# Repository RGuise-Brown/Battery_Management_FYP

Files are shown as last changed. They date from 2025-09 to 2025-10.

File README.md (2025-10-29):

# Battery Monitoring System for Lithium Thionyl Chloride Batteries

A battery monitoring system designed to track the health and state of charge of lithium thionyl chloride batteries operating in extreme cold conditions in the Southern Ocean Marginal Ice Zone (SO MIZ).

## Project Overview

This project was completed as a final year project (EEE4022S) for a Mechatronics Engineering degree at the University of Cape Town (UCT) in 2025.

**Author**: Rachael Guise-Brown  
**Supervisor**: Robyn Verrinder  
**Institution**: University of Cape Town

## Application

This battery monitoring system was designed for the **SHARC (Southern Hemisphere Antarctic Research Collective) Buoy**, which operates in the Southern Ocean Marginal Ice Zone. The system focuses on monitoring battery health in extreme cold conditions and adjusts the expected state of charge based on temperature changes.

## Battery Technology

Lithium thionyl chloride (Li-SOCl₂) batteries present unique monitoring challenges:
- **Primary battery** (non-rechargeable)
- **Very flat voltage discharge curve** - voltage alone is insufficient for accurate SOC estimation
- **Temperature-dependent performance** - capacity varies significantly with temperature

Due to these characteristics, the system uses **coulomb counting** and other methods to estimate state of charge, particularly important in the cold operating conditions of the Southern Ocean.

## System Features

### Hardware
- **INA226 Power Monitor**: Fully implemented and calibrated for accurate current and power measurement
- **BQ35100 Fuel Gauge**: Partial implementation but challenges with calibration and configuration without evaluation module (EVM)
- **Temperature Monitoring**: Three sensors tested
  - TMP117 digital I2C sensor
  - TMP36 (TO-92) analog sensor
  - TMP36 with shutdown (SOT-23) analog sensor (chosen sensor)
- **STM32 Nucleo-L4R5ZI**: Main microcontroller platform

### Firmware
- Real-time current, voltage, and capacity monitoring
- Temperature-compensated state of charge estimation
- Multiple algorithm implementations for data analysis
- I2C communication with all sensors
- Support for BQ35100 mode switching (EOS/ACC)
- Discharge cycle testing capabilities

## Repository Structure

```
├── firmware/          # Embedded C code for STM32
├── hardware/          # KiCad PCB designs and schematics
└── docs/              # Datasheets and reference documentation
```

## Implementation Status

### Fully Implemented ✓
- INA226 power monitor with calibration
- Temperature sensor array (TMP117, TMP36 sensors)
- BQ35100 basic functionality:
  - Current, voltage, and capacity reading
  - Mode switching (EOS ↔ ACC)
  - EOS impedance measurements (uncalibrated)
- Real-time monitoring algorithms
- Temperature-compensated SOC estimation

### Known Limitations
- BQ35100 I2C calibration is not functional through firmware

## Getting Started

### Hardware Setup
1. Review the hardware designs in `/hardware`
2. Assemble or obtain the custom PCBs:
   - BQ35100 fuel gauge board
   - Temperature sensor board
   - STM32 Nucleo Hat with INA226
3. Connect boards to STM32 Nucleo-L4R5ZI

### Firmware Setup
1. Navigate to `/firmware` directory
2. Build and flash the firmware to the STM32 Nucleo-L4R5ZI
3. Configure parameters as needed for your battery specifications

### Documentation
Refer to `/docs` for component datasheets and reference materials.

## Key Technologies

- **Microcontroller**: STM32L4R5ZI (ARM Cortex-M4)
- **Development Environment**: ARM GCC toolchain, STM32CubeIDE
- **Hardware Design**: KiCad
- **Communication Protocols**: I2C, UART
- **Programming Language**: C

## License

This project is licensed under the MIT License - see the LICENSE file for details.

## Acknowledgments

- **Robyn Verrinder** - Project supervisor
- **University of Cape Town** - Department of Electrical Engineering
- **SHARC Project** - Application context and requirements
- **Texas Instruments** - BQ35100 and INA226 reference designs

## Contact

Rachael Guise-Brown  
University of Cape Town  
2025

---

*Final Year Project (EEE4022S) - Mechatronics Engineering*  
*University of Cape Town*

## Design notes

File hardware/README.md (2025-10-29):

# Hardware Documentation

Hardware design files for the Battery Monitoring System, including custom PCB designs created in KiCad.

## Overview

Three main PCB designs that integrate with an STM32 Nucleo-L4R5ZI development board to create a complete battery monitoring solution.

## PCB Designs

### 1. STM32 Nucleo Hat (STM_Nucleo_Hat)
Board borrowed from ARU that contains INA226 power monitor which is the only component used in this project.

**Files**: Located in `/STM_Nucleo_Hat/` directory

---

### 2. BQ35100 Board (FYP_PMIC)
Custom board featuring the Texas Instruments BQ35100 fuel gauge for battery monitoring.

**Files**: Located in `/FYP_PMIC/` directory

---

### 3. Temperature Sensor Board (FYP_temp)
Custom board with three temperature sensors:
- TMP117 (digital I2C sensor)
- TMP36 (TO-92 analog sensor)
- TMP36 with shutdown (SOT-23 analog sensor)

**Files**: Located in `/FYP_temp/` directory

---

## Schematics

Full schematics are provided in both PDF and image formats for easy viewing:

### BQ35100 Board
- `BQ35100 Schematic.pdf` - Full schematic documentation
- `BQ35100 Schematic.png` - Quick reference image

### INA226 Board
- `INA226 Full Board Schematic.pdf` - Complete board schematic
- `INA226 Schematic.jpeg` - Quick reference image

### Temperature Sensor Board
- `Temp Board Schematic.pdf` - Full schematic documentation
- `Temp Schematic.png` - Quick reference image

## KiCad Component Files

Custom component libraries and footprints are located in the `/KiCad component files/` directory. These include:
- Custom symbols for BQ35100, INA226, and temperature sensors

## Design Tools

**Software**: KiCad 6.0 or later

## Getting Started

Open the `.kicad_pro` file in the respective board directory, or view the PDF schematics directly.

## Component Information

**Key ICs Used**:
- INA226 power monitor (on STM Nucleo Hat)
- BQ35100 fuel gauge
- TMP117 digital temperature sensor
- TMP36 analog temperature sensors (x2)

**Microcontroller**: STM32 Nucleo-L4R5ZI development board

## Notes

- INA226 is fully implemented and calibrated
- BQ35100 has partial implementation (see firmware README for details)
- All designs created in KiCad

---

For firmware documentation, see the main repository README.

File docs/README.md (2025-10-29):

# Documentation & Datasheets

Reference documentation and datasheets for components used in the Battery Monitoring System.

## Component Datasheets

### Battery Monitoring ICs
- **bq35100.pdf** - Texas Instruments BQ35100 fuel gauge datasheet
- **ina226.pdf** - Texas Instruments INA226 power monitor datasheet
- **ina219.pdf** - Texas Instruments INA219 power monitor datasheet

### Temperature Sensors
- **tmp117.pdf** - TMP117 digital temperature sensor datasheet
- **tmp36.pdf** - TMP36 analog temperature sensor datasheet

### Microcontroller
- **stm32l4r5vi.pdf** - STM32L4R5VI microcontroller datasheet
- **nucleo-l4r5zi-p.pdf** - STM32 Nucleo-L4R5ZI development board datasheet

## Reference Documents

### Texas Instruments Application Notes
- **sluubh1c.pdf** - BQ35100 technical reference
- **sluubh7.pdf** - BQ35100 application guide

### STM32 Documentation
- **um2179-stm32-nucleol44-boards-mb1312-stmicroelectronics.pdf** - STM32 Nucleo board user manual
- **rm0432-stm32l4-series-advanced-armbased-32bit-mcus-stmicroelectroni...** - STM32L4 series reference manual (memory mapping)

## Usage

Refer to these datasheets when:
- Configuring hardware components
- Understanding I2C communication protocols
- Setting up calibration parameters
- Troubleshooting hardware issues
- Designing custom PCBs

---

For hardware designs, see the hardware folder. For firmware implementation, see the main repository README.

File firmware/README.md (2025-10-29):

# Battery Monitoring System

A comprehensive battery monitoring system implementation with support for multiple temperature sensors, INA226 power monitor, and BQ35100 fuel gauge integration for real-time battery parameter tracking and analysis.

## Overview

This project implements a complete battery monitoring system designed for embedded applications. It provides real-time battery voltage, current, capacity, and temperature monitoring with support for multiple sensor types and monitoring algorithms.

## Key Features

- **Multi-Sensor Temperature Monitoring**: 
  - TMP117 digital temperature sensor
  - TMP36 (TO-92 package) analog temperature sensor
  - TMP36 with shutdown (SOT-23 package) analog temperature sensor
- **INA226 Power Monitor**: Fully implemented and calibrated for accurate current and power measurement
- **BQ35100 Fuel Gauge**: Partial implementation with working features:
  - Current, voltage, and capacity readings
  - Mode switching between EOS (End-of-Service) and ACC (Accumulator) modes
  - EOS impedance and scaled impedance measurement
  - Note: I2C calibration not yet functional
- **Real-time Monitoring**: Continuous battery voltage, current, and temperature tracking
- **Advanced Algorithms**: Multiple monitoring algorithm implementations for data analysis
- **I2C Communication**: Robust I2C interface for all sensor communication
- **Temperature Protection**: Multi-point temperature sensing with threshold monitoring
- **Discharge Cycle Testing**: Automated discharge cycle testing capabilities
- **System Monitoring**: Comprehensive system health monitoring and logging

## Project Structure

### Core Monitoring Files
Uses the individual component files to create a single file that reads all of the values.

- **bms_monitor_reduced.c/h** -  Monitoring implementation for INA226 and TMP36 (SOT-23)
- **bms_monitor.c/h** - Monitoring implementation for BQ35100 and TMP36 (SOT-23)

### Core Algorithm Files
Monitoring algorithms to track, temperature adjusted state-of-charge, voltage drop during high current transmissions, voltage throughout discharge and temperature trend
- **bms_algorithms_v2.c/h** - Version 2 of monitoring algorithms with improvements
- **bms_algorithms.c/h** - Monitoring algorithm implementation version 1, designed for BQ35100 with EOS but not fully tested without EOS calibration

### Hardware Interface

#### Battery Monitoring ICs

**INA226 Power Monitor** (Fully Implemented ✓)
- **ina226_i2c1.c/h** - Complete INA226 interface with calibration
- Accurate current, voltage, and power measurements
- Fully calibrated and operational

**BQ35100 Fuel Gauge** (Partially Implemented)
- **bq35100_i2c_acc.c/h** - BQ35100 accumulator mode interface
- **bq35100_i2c_eos.c/h** - BQ35100 end-of-service mode interface
- **bq35100_common.h** - Common definitions for BQ35100
- Working features:
  - Current, voltage, and capacity reading
  - Mode switching (EOS ↔ ACC)
  - EOS impedance and scaled impedance measurement
- Known limitations:
  - I2C calibration not functional

#### Temperature Sensors

- **TMP117** - Digital I2C temperature sensor
- **TMP36 (TO-92)** - Analog temperature sensor
- **TMP36 with Shutdown (SOT-23)** - Analog temperature sensor with power control

#### Communication Interfaces

- **i2c.c/h** - Generic I2C communication layer
- **i2c_temp.c/h** - I2C temperature sensor interface
- **adc_temp.c/h** - ADC-based temperature measurement (for analog sensors)

### Monitoring & Testing

- **battery_monitor.c/h** - Main battery monitoring module
- **battery_monitor_reduced.h** - Reduced footprint monitoring
- **system_monitoring.c/h** - Overall system health monitoring
- **discharge_cycle_test.c/h** - Automated discharge testing
- **rapid_transmission_test.c** - High-speed data transmission testing
- **monitoring_testing.c** - Monitoring system validation

### System Components

- **main.c** - Main application entry point
- **clock_config.c/h** - System clock configuration
- **uart.c/h** - UART communication interface
- **led.c/h** - LED status indicators
- **syscalls.c** - System call implementations
- **systick_timing.c/h** - System tick timing utilities

### Utilities

- **adc_temp.c/h** - ADC-based temperature measurement
- **temp_sensor_enable.c/h** - Temperature sensor control
- **temp_threshold_test.c/h** - Temperature threshold testing

## Hardware Requirements

### Microcontroller
- STM32 Microcontroller (configured via clock_config)

### Battery Monitoring ICs
- **INA226** - Power monitor (fully supported)
- **BQ35100** - Fuel gauge (partial support)

### Temperature Sensors
- **TMP117** - Digital I2C temperature sensor
- **TMP36 (TO-92)** - Analog temperature sensor
- **TMP36 (SOT-23)** - Analog temperature sensor with shutdown capability

### Peripherals
- LED indicators for status
- UART interface for debugging and data output

## Getting Started

### Prerequisites

- ARM GCC toolchain
- STM32 development environment
- Hardware setup with required sensors

### Building

```bash
# Clone the repository
git clone [your-repo-url]

# Build the project
make all
```

### Configuration

1. Configure clock settings in `clock_config.c`
2. Set up I2C bus parameters in `i2c.c`
3. Configure monitoring algorithm parameters in `bms_algorithms.h`
4. Adjust temperature thresholds in `temp_threshold_test.h`
5. Calibrate INA226 settings in `ina226_i2c1.c` (already calibrated)
6. Configure BQ35100 mode settings (EOS/ACC) as needed

**Note**: BQ35100 I2C calibration is not currently functional and may require manual calibration through other means.

## Usage

The system initializes all peripherals and begins continuous monitoring upon startup. Battery data can be accessed via:

- UART interface for real-time debugging
- LED indicators for status
- System monitoring interface for detailed metrics

## Testing

The project includes several test modules:

- **Discharge Cycle Test**: Validates battery behavior during discharge
- **Rapid Transmission Test**: Tests high-speed data communication
- **Temperature Threshold Test**: Verifies thermal protection
- **Monitoring Testing**: Validates monitoring accuracy

## Algorithm Versions

This project contains multiple monitoring algorithm implementations:

- **Original** (`bms_algorithms.c`) - Initial implementation
- **Version 2** (`bms_algorithms_v2.c`) - Refined algorithms with improved accuracy

## Implementation Status

### Fully Implemented ✓
- INA226 power monitor with calibration
- TMP117 digital temperature sensor
- TMP36 analog temperature sensors (both variants)
- Mode switching for BQ35100 (EOS/ACC)
- Basic BQ35100 reading (current, voltage, capacity)
- EOS impedance measurements

### Partially Implemented ⚠️
- BQ35100 I2C calibration (not functional)

## Acknowledgments

- Texas Instruments for BQ35100 documentation
- STMicroelectronics for STM32 support

---

**Last Updated**: October 2025

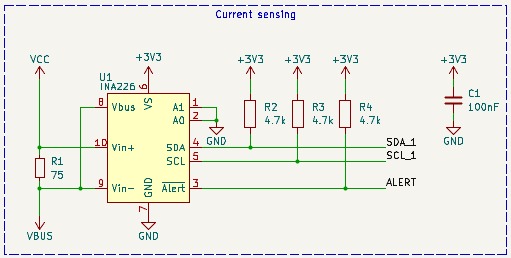
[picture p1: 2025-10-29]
hardware/INA226 Schematic.jpeg

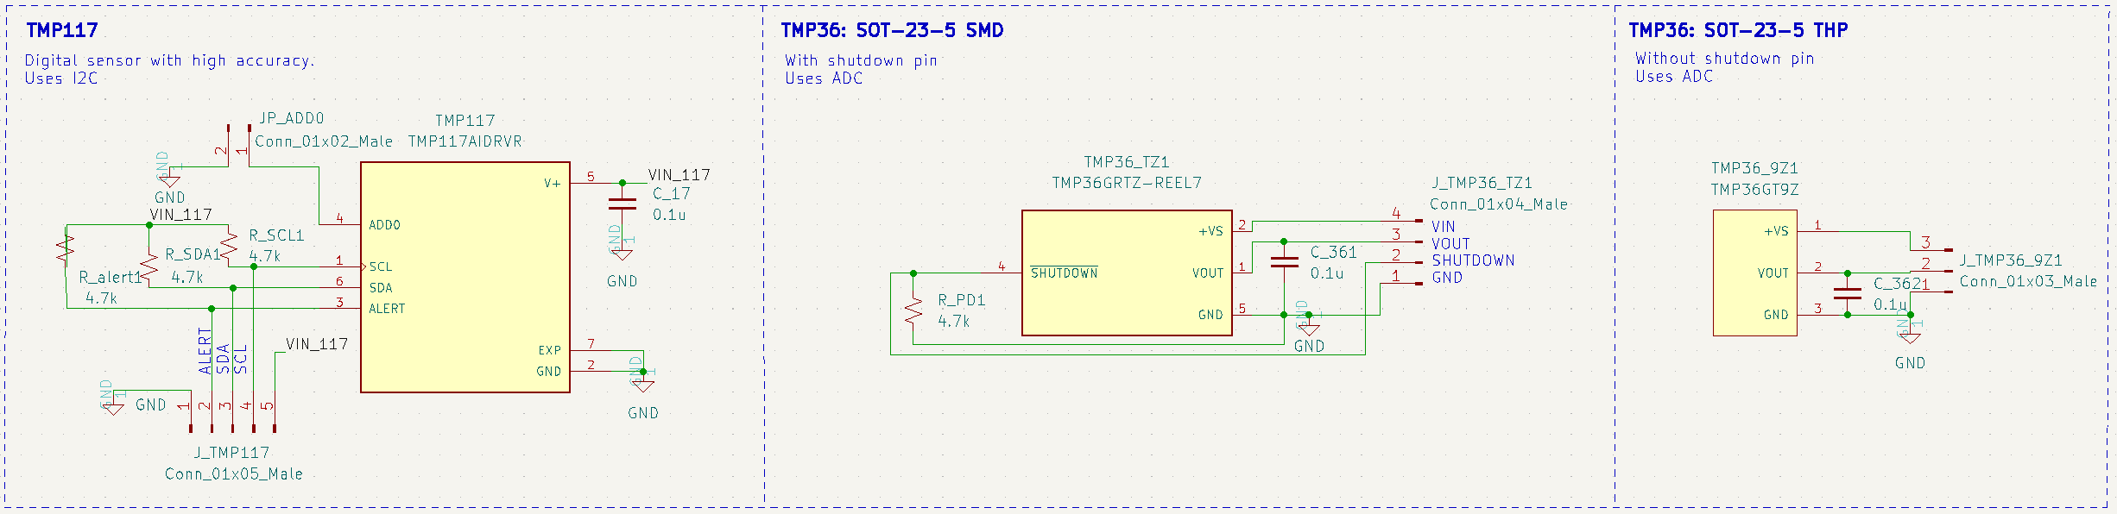
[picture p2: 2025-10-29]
hardware/Temp Schematic.png

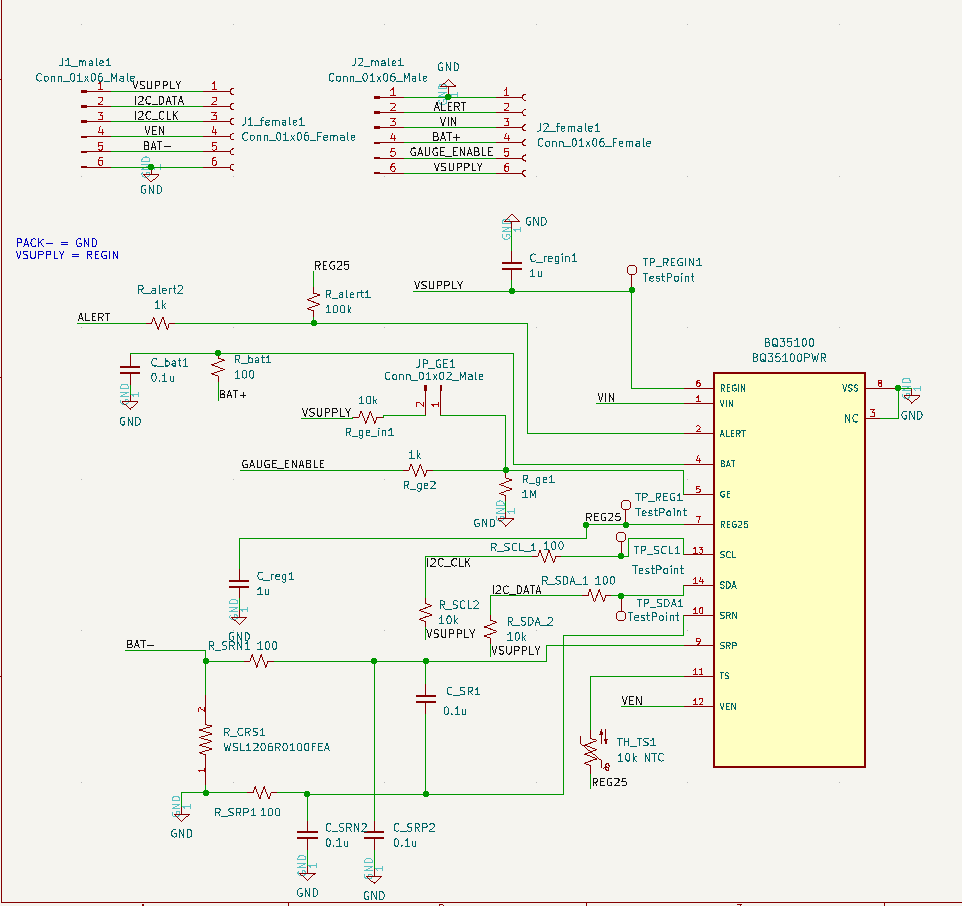
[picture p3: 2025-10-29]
hardware/BQ35100 Schematic.png

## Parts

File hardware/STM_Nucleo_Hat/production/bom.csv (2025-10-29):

Designator | Footprint | Quantity | Value | LCSC Part #
C1, C2 | 0603 | 2 | 100nF | C14663
R1 | 0805 | 1 | 75 | C3033913
R2, R3, R4 | 0603 | 3 | 4.7k | C23162
U1 | MSOP-10_3x3mm_P0.5mm | 1 | INA226 | C49851

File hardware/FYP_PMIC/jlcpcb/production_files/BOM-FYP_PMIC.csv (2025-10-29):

Comment | Designator | Footprint | LCSC
0.1u | C_SR1,C_SRN2,C_SRP2,C_bat1 | C_0402_1005Metric | C1525
1u | C_reg1,C_regin1 | C_0603_1608Metric | C15849
100 | R_SCL_1,R_SDA_1,R_SRN1,R_SRP1,R_bat1 | R_0805_2012Metric | C17408
10k | R_SCL2,R_SDA_2,R_ge_in1 | R_0805_2012Metric | C17414
100k | R_alert1 | R_1206_3216Metric | C17900
1M | R_ge1 | R_1206_3216Metric | C17927
1k | R_alert2,R_ge2 | R_1206_3216Metric | C4410
BQ35100PWR | BQ35100 | SOP65P640X120-14N | C469863
WSL1206R0100FEA | R_CRS1 | RESC3216X90 | C843879
TestPoint | TP_SCL1 | TestPoint_Pad_D2.0mm
10k NTC | TH_TS1 | C_Disc_D5.0mm_W2.5mm_P2.50mm
Conn_01x06_Female | J2_female1 | PinSocket_1x06_P2.54mm_Vertical
TestPoint | TP_REGIN1 | TestPoint_Pad_D2.0mm
Conn_01x02_Male | JP_GE1 | PinHeader_1x02_P2.54mm_Vertical
Conn_01x06_Male | J1_male1 | PinHeader_1x06_P2.54mm_Vertical
TestPoint | TP_REG1 | TestPoint_Pad_D2.0mm
TestPoint | TP_SDA1 | TestPoint_Pad_D2.0mm
Conn_01x06_Male | J2_male1 | PinHeader_1x06_P2.54mm_Vertical
Conn_01x06_Female | J1_female1 | PinSocket_1x06_P2.54mm_Vertical

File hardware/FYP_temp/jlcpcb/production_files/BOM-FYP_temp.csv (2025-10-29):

Comment | Designator | Footprint | LCSC
0.1u | C_17,C_361,C_362 | C_0402_1005Metric | C1525
4.7k | R_PD1,R_SCL1,R_SDA1,R_alert1 | R_0603_1608Metric | C23162
TMP36GT9Z | TMP36_9Z1 | TO92127P521H733-3 | C5692995
TMP36GRTZ-REEL7 | TMP36_TZ1 | SOT95P280X145-5N | C5692996
TMP117AIDRVR | TMP117 | SON65P200X200X80-7N | C699536
Conn_01x04_Male | J_TMP36_TZ1 | PinHeader_1x04_P2.54mm_Vertical
Conn_01x02_Male | JP_ADD0 | PinHeader_1x02_P2.54mm_Vertical
Conn_01x05_Male | J_TMP117 | PinHeader_1x05_P2.54mm_Vertical
Conn_01x03_Male | J_TMP36_9Z1 | PinHeader_1x03_P2.54mm_Vertical

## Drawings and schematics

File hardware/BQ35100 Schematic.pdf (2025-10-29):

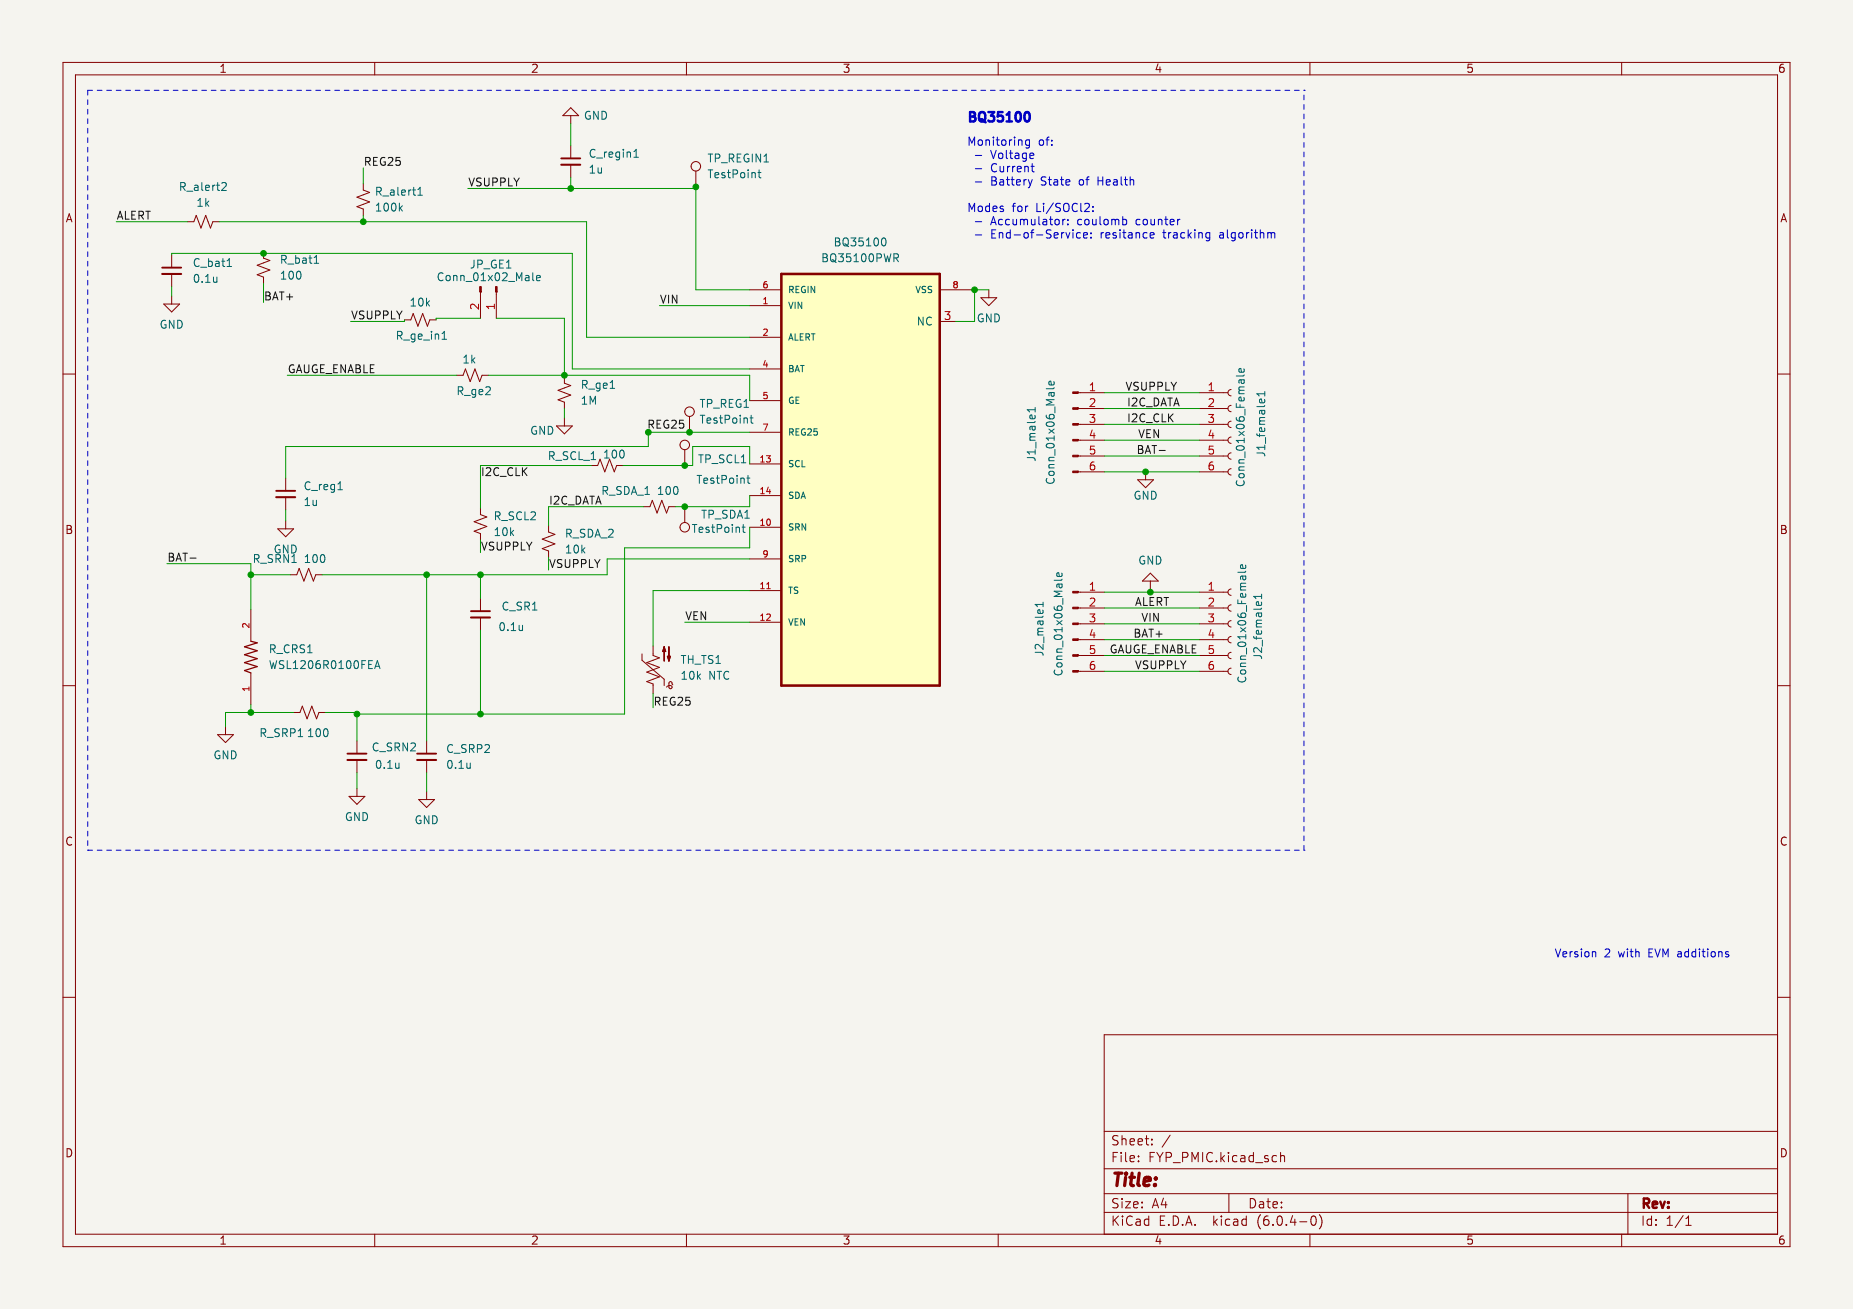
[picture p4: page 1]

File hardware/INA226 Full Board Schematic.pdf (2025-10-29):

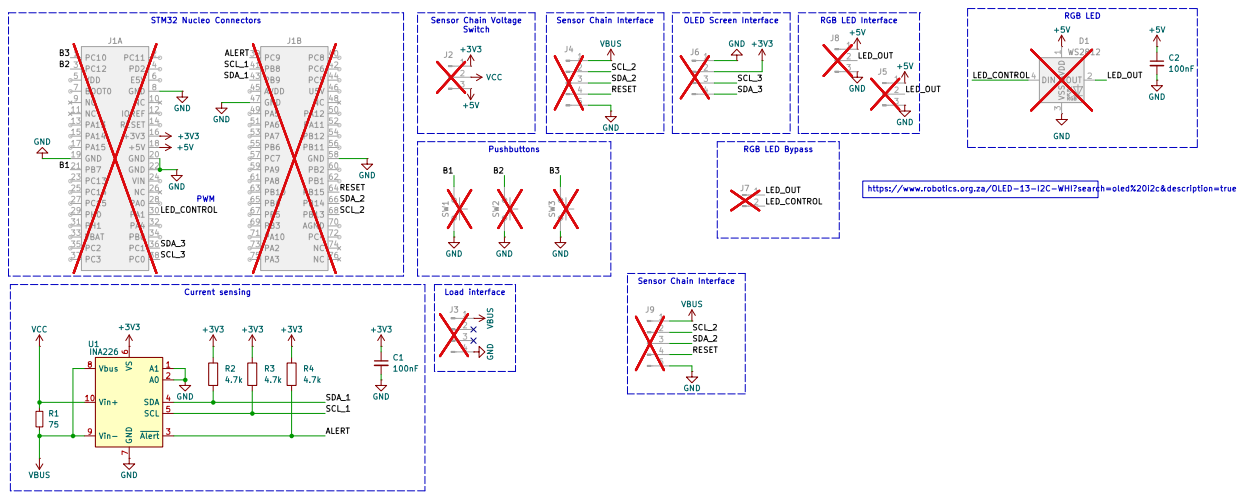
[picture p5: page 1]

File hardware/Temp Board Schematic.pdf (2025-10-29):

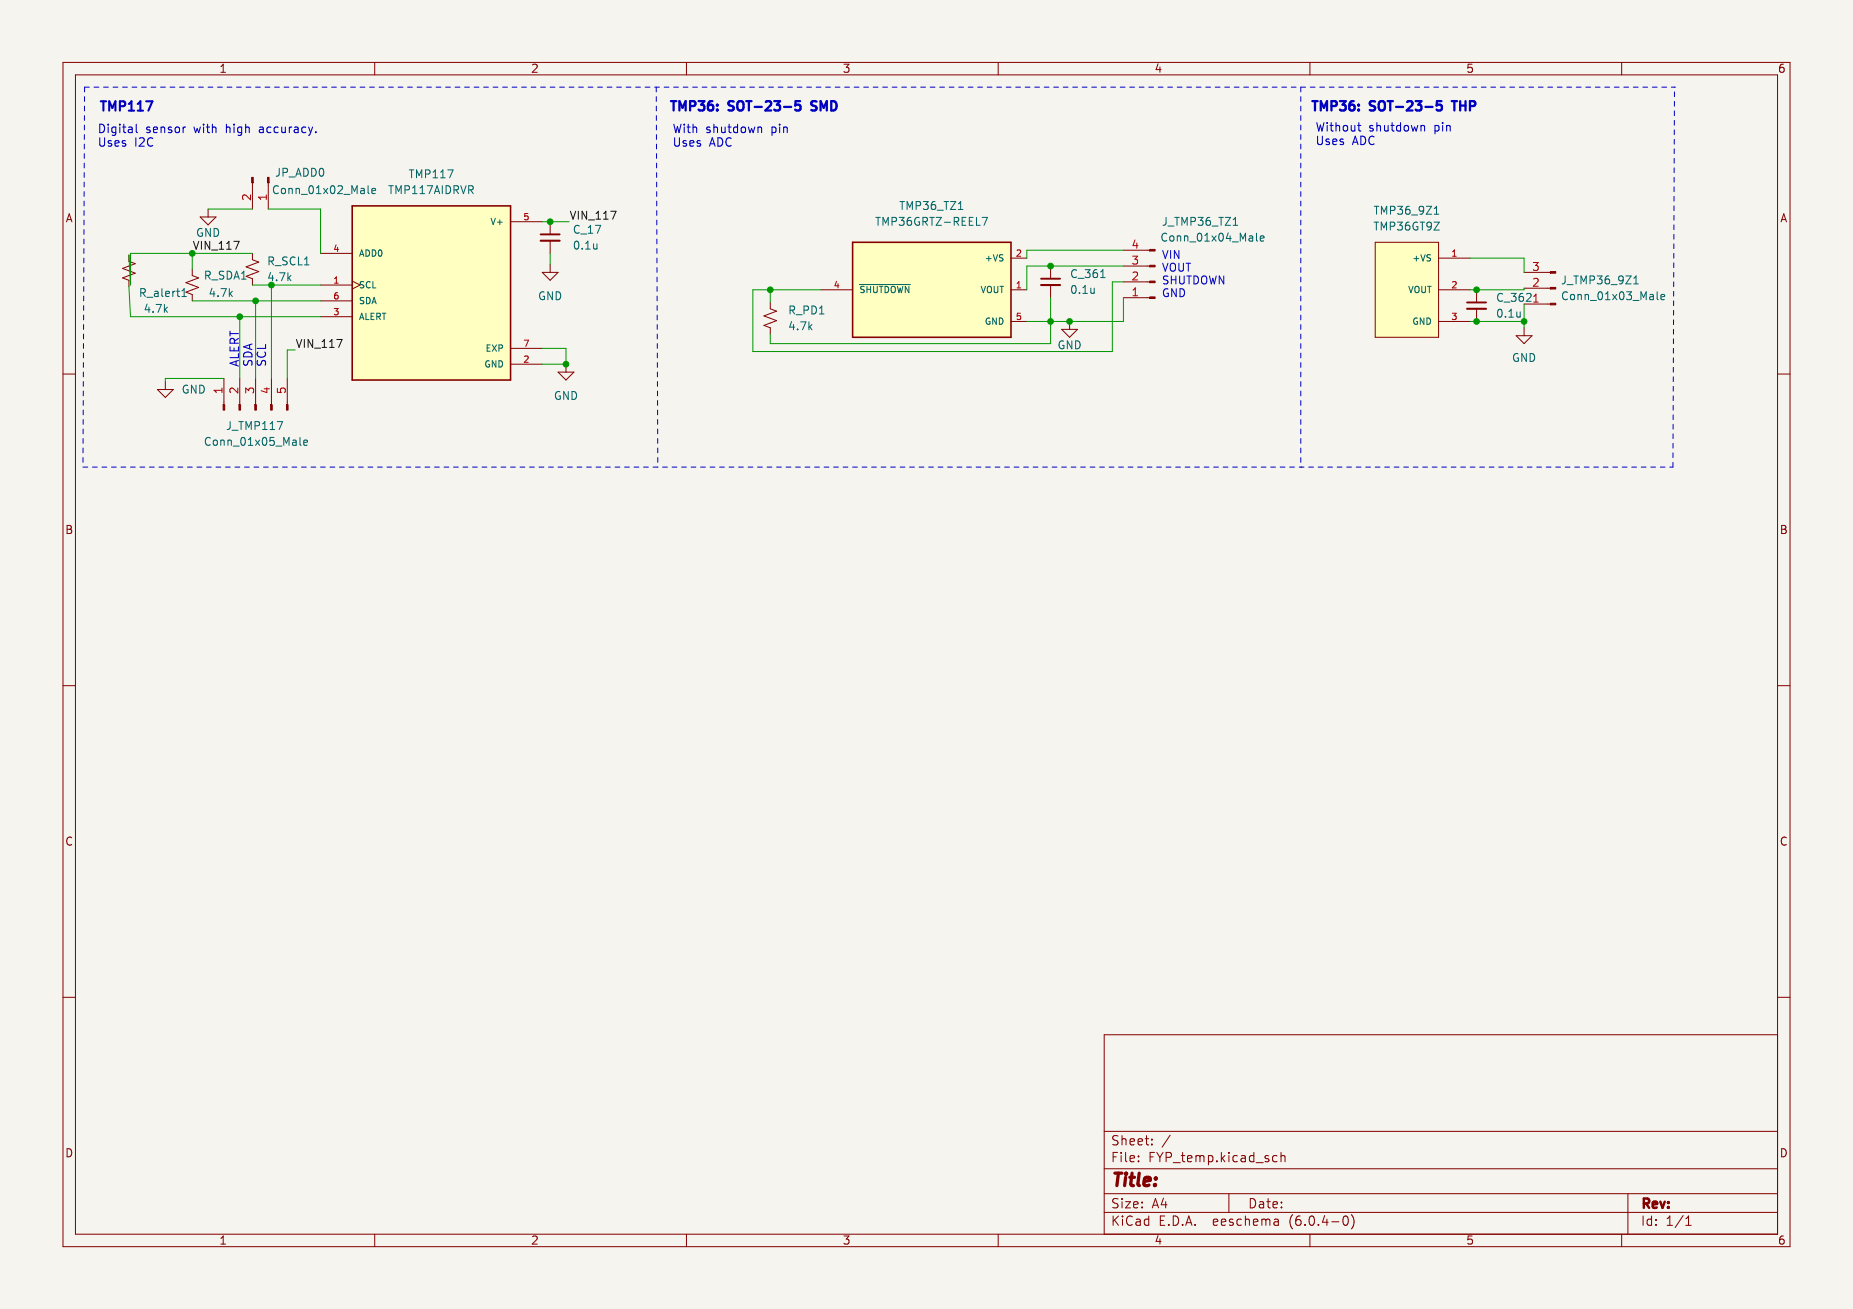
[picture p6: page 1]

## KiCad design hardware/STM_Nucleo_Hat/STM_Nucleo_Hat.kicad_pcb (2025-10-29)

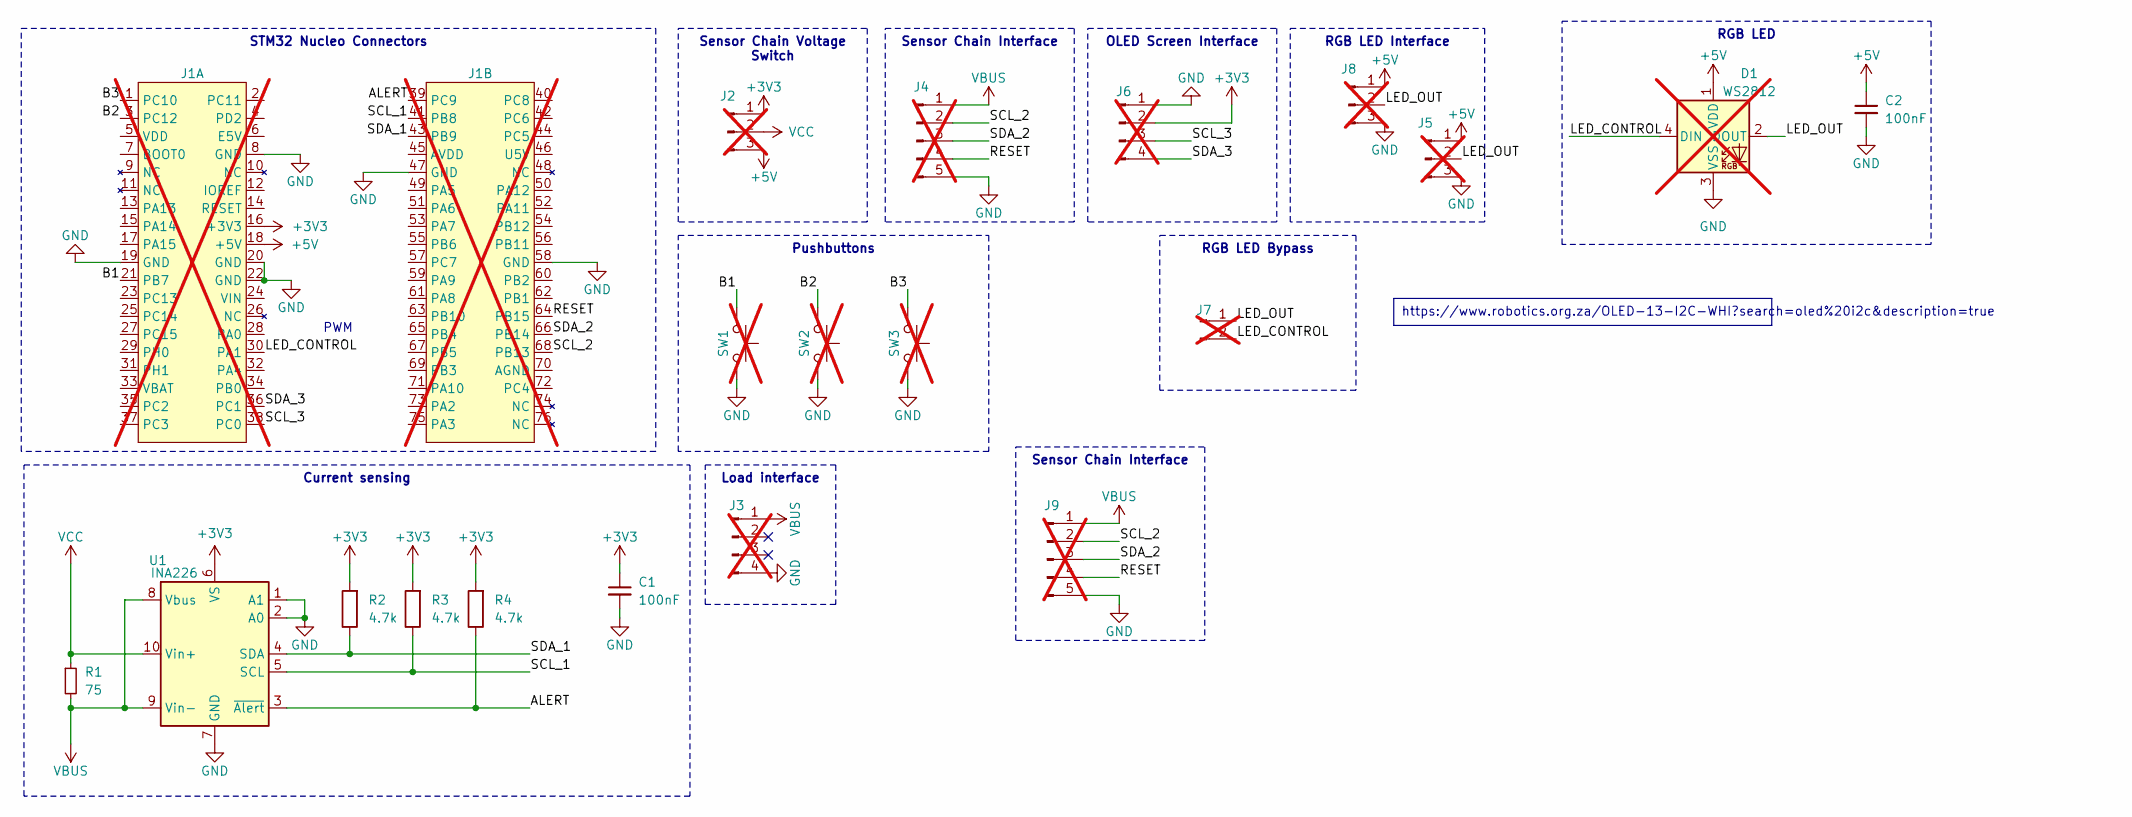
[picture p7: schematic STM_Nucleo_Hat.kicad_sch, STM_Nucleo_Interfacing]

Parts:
C1, C2: 100nF; C_0603_1608Metric; LCSC C14663
D1: WS2812; LED_WS2812B_PLCC4_5.0x5.0mm_P3.2mm; LCSC C2843785; not fitted
J1: Nucleo64-Pins; not fitted
J2, J5, J8: Conn_01x03_Pin; PinHeader_1x03_P2.54mm_Vertical; not fitted
J3: Conn_01x05_Pin; PinHeader_1x04_P2.54mm_Vertical; not fitted
J4, J9: Conn_01x05_Pin; PinHeader_1x05_P2.54mm_Vertical; not fitted
J6: Conn_01x05_Pin; 1.3_OLED_Screen; not fitted
J7: Conn_01x02_Pin; PinHeader_1x02_P2.54mm_Vertical; not fitted
R1: 75; C_0805_2012Metric_Pad1.18x1.45mm_HandSolder; LCSC C3033913
R2, R3, R4: 4.7k; R_0603_1608Metric; LCSC C23162
SW1, SW2, SW3: SW_Push; SW_PUSH_6mm; not fitted
U1: INA226; MSOP-10_3x3mm_P0.5mm; LCSC C49851

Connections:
+3V3: C1.1, J1.16 (+3V3), J2.1, J6.2, R2.2, R3.2, R4.2, U1.6 (VS)
+5V: C2.1, D1.1 (VDD), J1.18 (+5V), J2.3, J5.1, J8.1
/ALERT: J1.39 (PC9), R4.1, U1.3 (~Alert)
/B1: J1.21 (PB7), SW1.1
/B2: J1.3 (PC12), SW2.1
/B3: J1.1 (PC10), SW3.1
/LED_CONTROL: D1.4 (DIN), J1.30 (PA1), J7.2
/LED_OUT: D1.2 (DOUT), J5.2, J7.1, J8.2
/RESET: J1.64 (PB15), J4.4, J9.4
/SCL_1: J1.41 (PB8), R3.1, U1.5 (SCL)
/SCL_2: J1.68 (PB13), J4.2, J9.2
/SCL_3: J1.38 (PC0), J6.3
/SDA_1: J1.43 (PB9), R2.1, U1.4 (SDA)
/SDA_2: J1.66 (PB14), J4.3, J9.3
/SDA_3: J1.36 (PC1), J6.4
GND: C1.2, C2.2, D1.3 (VSS), J1.8 (GND), J1.19 (GND), J1.20 (GND), J1.22 (GND), J1.47 (GND), J1.58 (GND), J3.4, J4.5, J5.3, J6.1, J8.3, J9.5, SW1.2, SW2.2, SW3.2, U1.1 (A1), U1.2 (A0), U1.7 (GND)
VBUS: J3.1, J4.1, J9.1, R1.2, U1.8 (Vbus), U1.9 (Vin-)
VCC: J2.2, R1.1, U1.10 (Vin+)

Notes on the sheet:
Sensor Chain Interface
RGB LED
Pushbuttons
https://www.robotics.org.za/OLED-13-I2C-WHI?search=oled%20i2c&description=true
STM32 Nucleo Connectors
RGB LED Interface
Load interface
Current sensing
OLED Screen Interface
RGB LED Bypass
Sensor Chain Voltage Switch
PWM

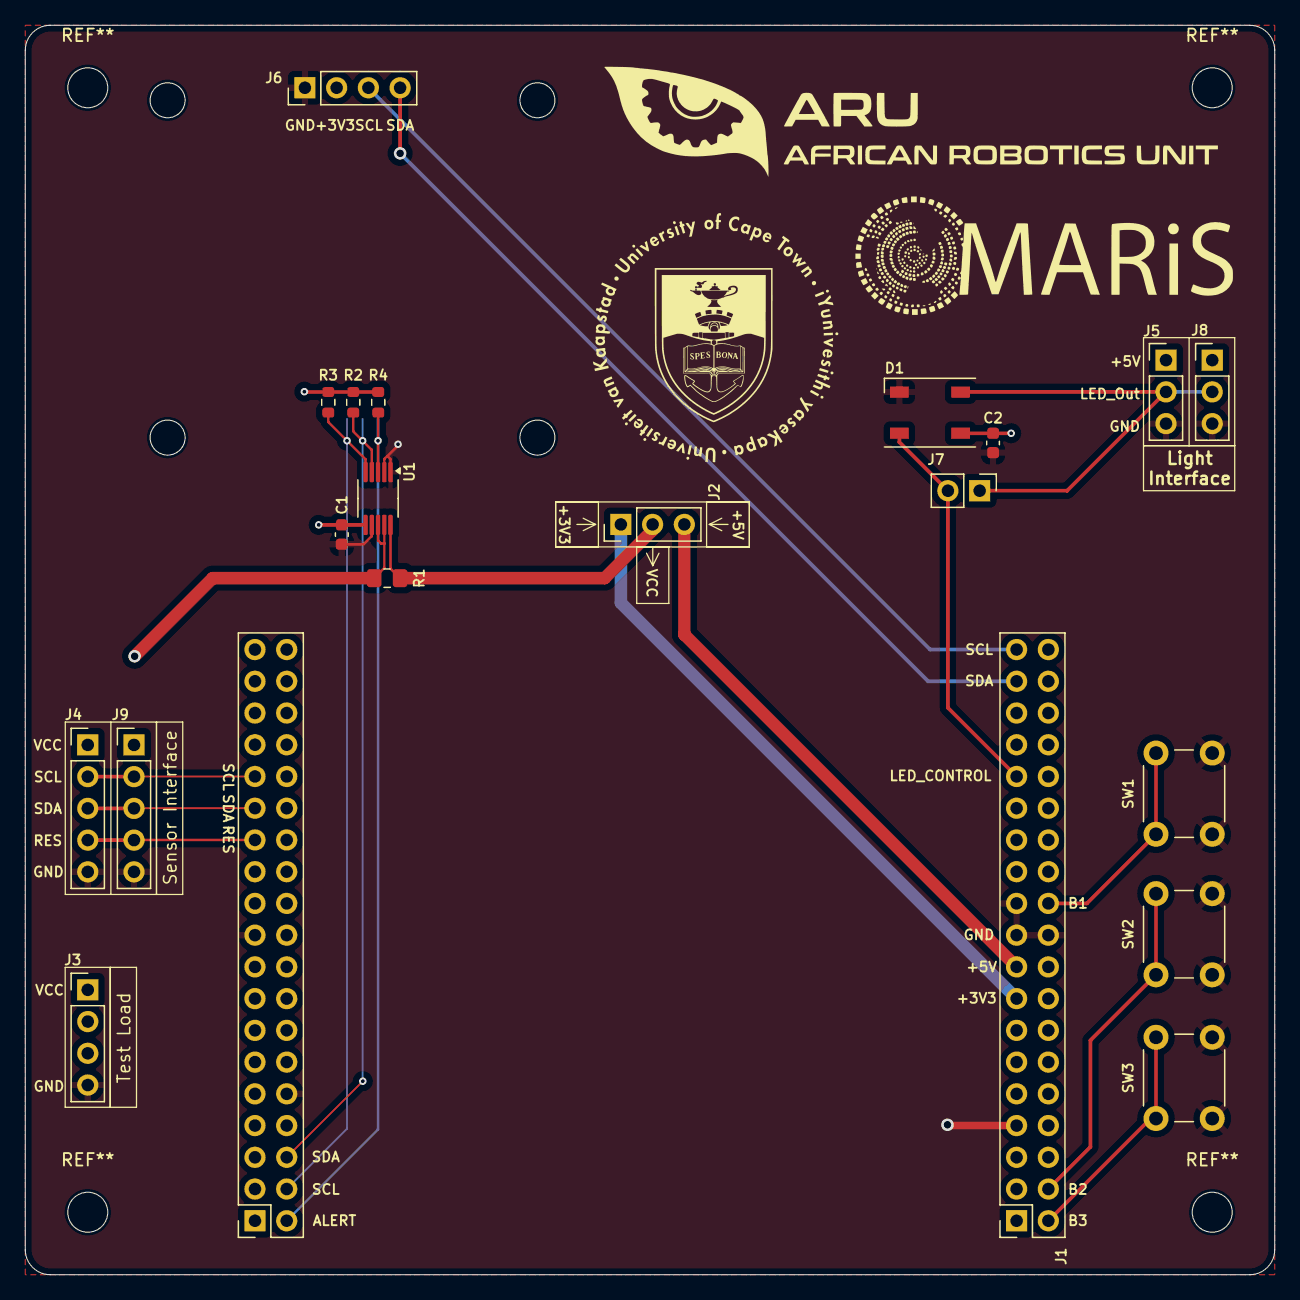
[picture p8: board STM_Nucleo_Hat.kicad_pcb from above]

Board: 4 copper layers, 100.0 x 100.0 mm, 20 parts (0 on the bottom side), 18 nets.

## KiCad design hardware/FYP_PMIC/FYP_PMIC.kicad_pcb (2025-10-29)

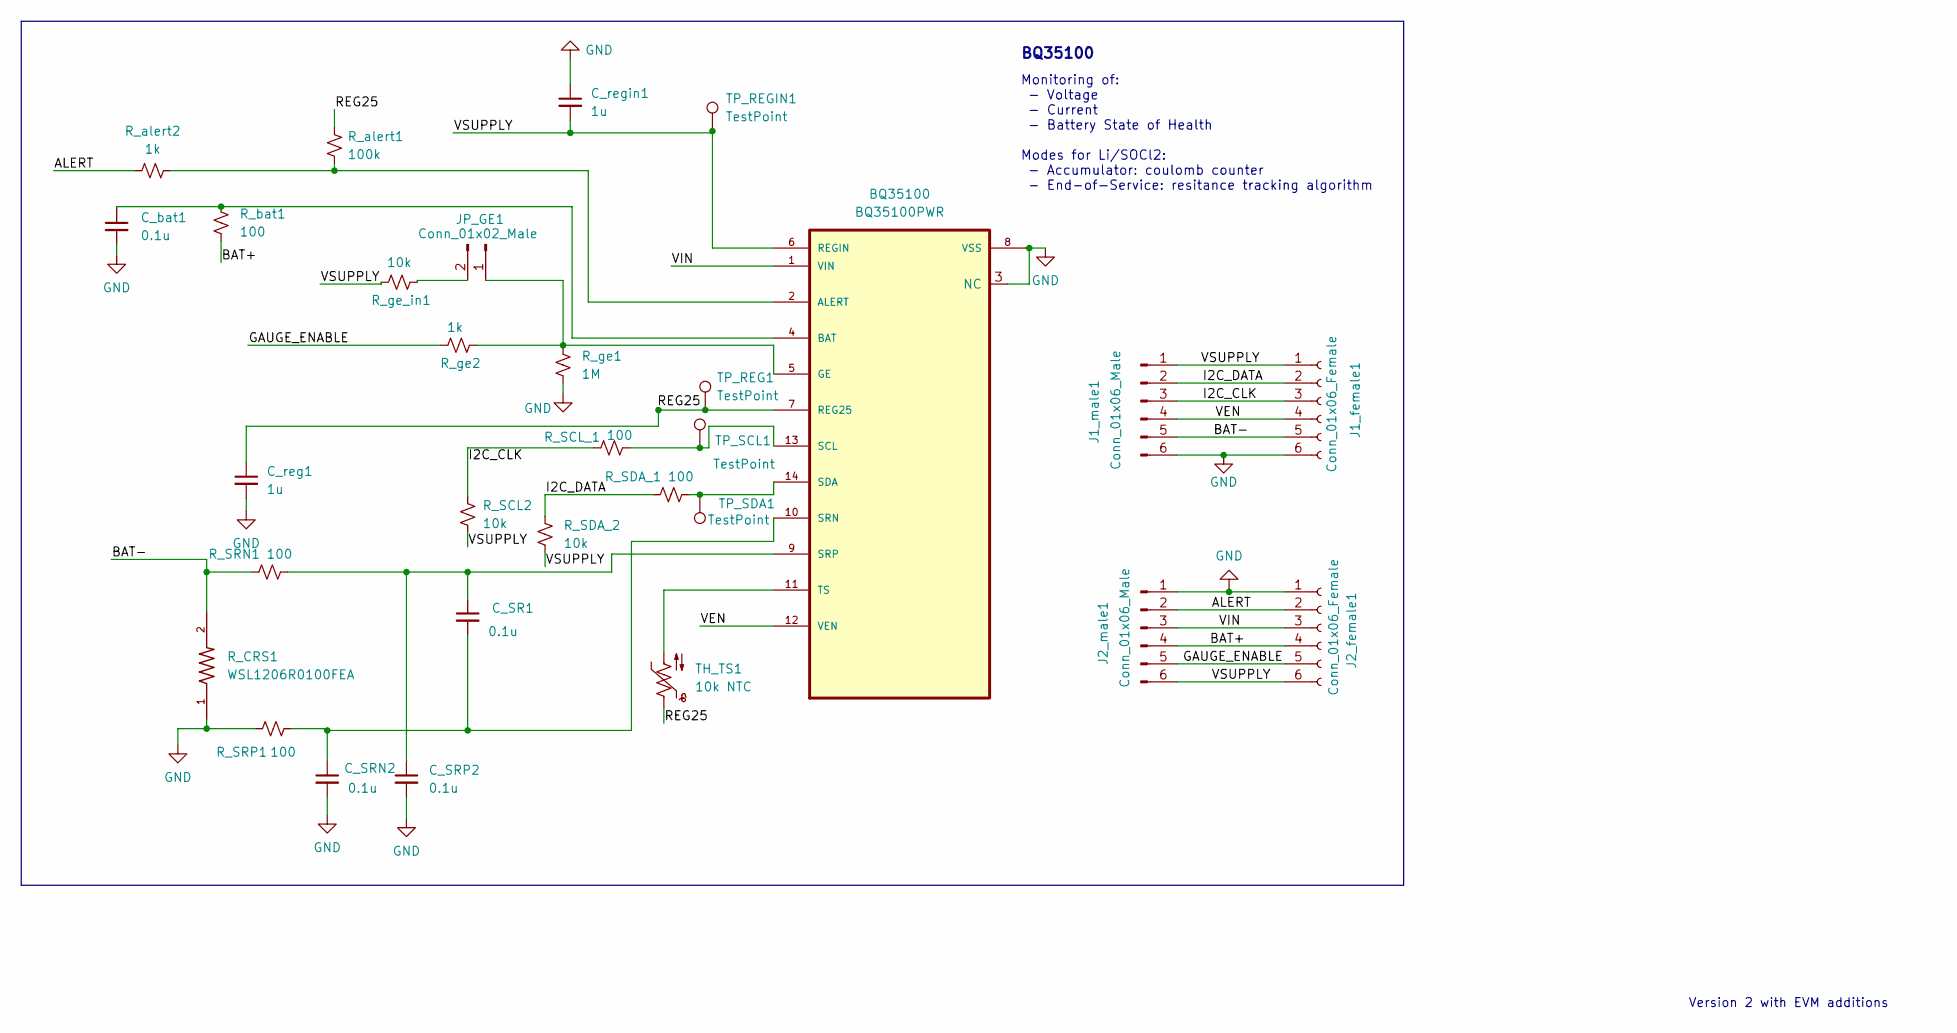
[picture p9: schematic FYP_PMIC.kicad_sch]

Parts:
BQ35100: BQ35100PWR; SOP65P640X120-14N; DigiKey_Part_Number 296-47251-1-ND
C_SR1: 0.1u; C_0402_1005Metric
C_SRN2: 0.1u; C_0402_1005Metric
C_SRP2: 0.1u; C_0402_1005Metric
C_bat1: 0.1u; C_0402_1005Metric
C_reg1: 1u; C_0603_1608Metric
C_regin1: 1u; C_0603_1608Metric
J1_female1, J2_female1: Conn_01x06_Female; PinSocket_1x06_P2.54mm_Vertical
J1_male1, J2_male1: Conn_01x06_Male; PinHeader_1x06_P2.54mm_Vertical
JP_GE1: Conn_01x02_Male; PinHeader_1x02_P2.54mm_Vertical
R_CRS1: WSL1206R0100FEA; RESC3216X90
R_SCL2: 10k; R_0805_2012Metric
R_SCL_1: 100; R_0805_2012Metric
R_SDA_1: 100; R_0805_2012Metric
R_SDA_2: 10k; R_0805_2012Metric
R_SRN1: 100; R_0805_2012Metric
R_SRP1: 100; R_0805_2012Metric
R_alert1: 100k; R_1206_3216Metric
R_alert2: 1k; R_1206_3216Metric
R_bat1: 100; R_0805_2012Metric
R_ge1: 1M; R_1206_3216Metric
R_ge2: 1k; R_1206_3216Metric
R_ge_in1: 10k; R_0805_2012Metric
TH_TS1: 10k NTC; C_Disc_D5.0mm_W2.5mm_P2.50mm
TP_REG1: TestPoint; TestPoint_Pad_D2.0mm
TP_REGIN1: TestPoint; TestPoint_Pad_D2.0mm
TP_SCL1: TestPoint; TestPoint_Pad_D2.0mm
TP_SDA1: TestPoint; TestPoint_Pad_D2.0mm

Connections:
/ALERT: J2_female1.2, J2_male1.2, R_alert2.1
/BAT+: J2_female1.4, J2_male1.4, R_bat1.2
/BAT-: J1_female1.5, J1_male1.5, R_CRS1.2, R_SRN1.1
/GAUGE_ENABLE: J2_female1.5, J2_male1.5, R_ge2.1
/I2C_CLK: J1_female1.3, J1_male1.3, R_SCL2.1, R_SCL_1.1
/I2C_DATA: J1_female1.2, J1_male1.2, R_SDA_1.1, R_SDA_2.1
/REG25: BQ35100.7 (REG25), C_reg1.1, R_alert1.1, TH_TS1.1, TP_REG1.1
/VEN: BQ35100.12 (VEN), J1_female1.4, J1_male1.4
/VIN: BQ35100.1 (VIN), J2_female1.3, J2_male1.3
/VSUPPLY: BQ35100.6 (REGIN), C_regin1.2, J1_female1.1, J1_male1.1, J2_female1.6, J2_male1.6, R_SCL2.2, R_SDA_2.2, R_ge_in1.1, TP_REGIN1.1
GND: BQ35100.3 (NC), BQ35100.8 (VSS), C_SRN2.2, C_SRP2.2, C_bat1.2, C_reg1.2, C_regin1.1, J1_female1.6, J1_male1.6, J2_female1.1, J2_male1.1, R_CRS1.1, R_SRP1.1, R_ge1.2
unnamed: BQ35100.2 (ALERT), R_alert1.2, R_alert2.2
unnamed: BQ35100.4 (BAT), C_bat1.1, R_bat1.1
unnamed: BQ35100.5 (GE), JP_GE1.1, R_ge1.1, R_ge2.2
unnamed: BQ35100.9 (SRP), C_SR1.1, C_SRP2.1, R_SRN1.2
unnamed: BQ35100.10 (SRN), C_SR1.2, C_SRN2.1, R_SRP1.2
unnamed: BQ35100.11 (TS), TH_TS1.2
unnamed: BQ35100.13 (SCL), R_SCL_1.2, TP_SCL1.1
unnamed: BQ35100.14 (SDA), R_SDA_1.2, TP_SDA1.1
unnamed: JP_GE1.2, R_ge_in1.2

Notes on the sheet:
BQ35100
Version 2 with EVM additions
Monitoring of: - Voltage - Current - Battery State of Health Modes for Li/SOCl2: - Accumulator: coulomb counter - End-of-Service: resitance tracking algorithm

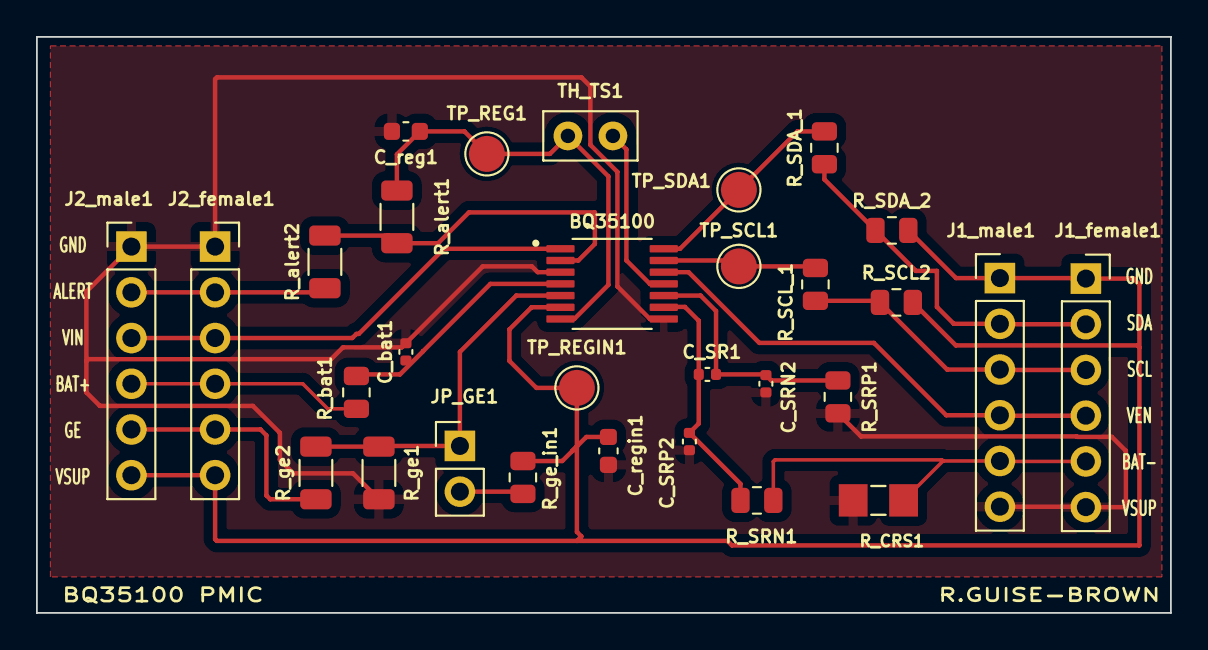
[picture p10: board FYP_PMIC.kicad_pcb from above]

Board: 2 copper layers, 63.0 x 32.0 mm, 30 parts (0 on the bottom side), 20 nets.

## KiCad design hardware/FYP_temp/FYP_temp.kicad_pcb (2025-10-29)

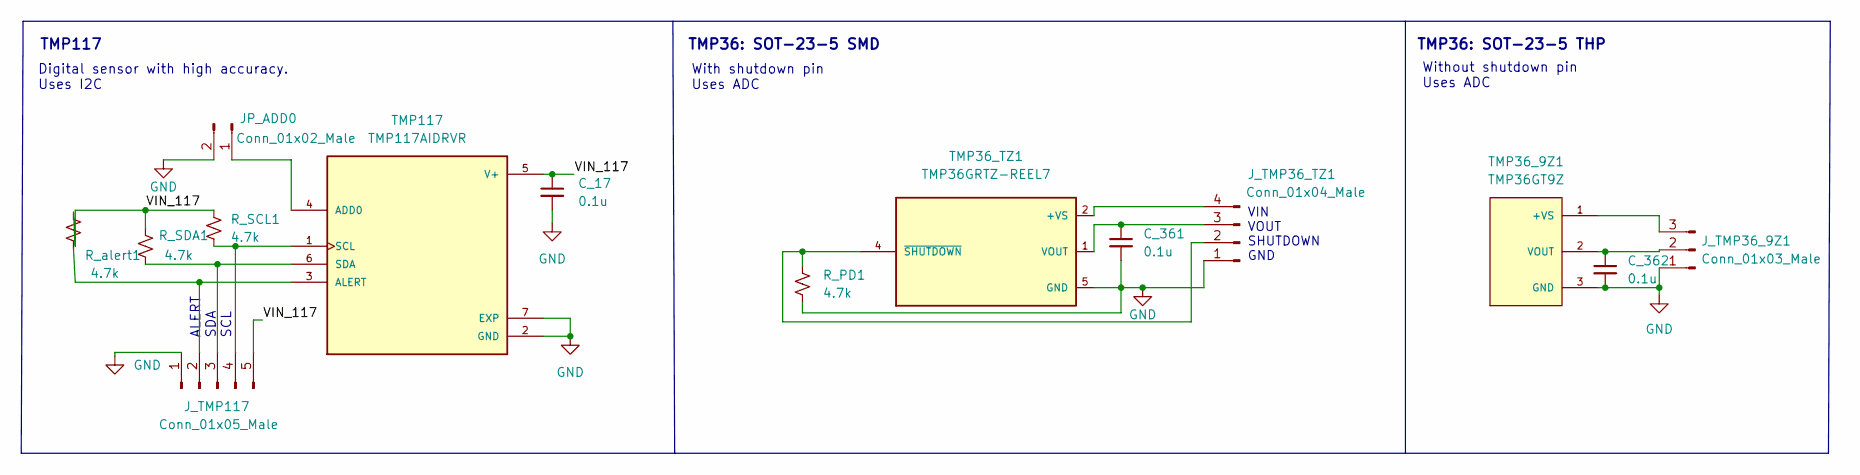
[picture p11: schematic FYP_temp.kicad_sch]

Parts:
C_17, C_361, C_362: 0.1u; C_0402_1005Metric
JP_ADD0: Conn_01x02_Male; PinHeader_1x02_P2.54mm_Vertical
J_TMP36_9Z1: Conn_01x03_Male; PinHeader_1x03_P2.54mm_Vertical
J_TMP36_TZ1: Conn_01x04_Male; PinHeader_1x04_P2.54mm_Vertical
J_TMP117: Conn_01x05_Male; PinHeader_1x05_P2.54mm_Vertical
R_PD1: 4.7k; R_0603_1608Metric
R_SCL1: 4.7k; R_0603_1608Metric
R_SDA1: 4.7k; R_0603_1608Metric
R_alert1: 4.7k; R_0603_1608Metric
TMP36_9Z1: TMP36GT9Z; TO92127P521H733-3; PARTREV H
TMP36_TZ1: TMP36GRTZ-REEL7; SOT95P280X145-5N; PARTREV H
TMP117: TMP117AIDRVR; SON65P200X200X80-7N; PARTREV B

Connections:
/VIN_117: C_17.1, J_TMP117.5, R_SCL1.1, R_SDA1.1, R_alert1.1, TMP117.5 (V+)
GND: C_17.2, C_361.2, C_362.2, JP_ADD0.2, J_TMP36_9Z1.1, J_TMP36_TZ1.1, J_TMP117.1, R_PD1.2, TMP36_9Z1.3 (GND), TMP36_TZ1.5 (GND), TMP117.2 (GND), TMP117.7 (EXP)
unnamed: C_361.1, J_TMP36_TZ1.3, TMP36_TZ1.1 (VOUT)
unnamed: C_362.1, J_TMP36_9Z1.2, TMP36_9Z1.2 (VOUT)
unnamed: JP_ADD0.1, TMP117.4 (ADD0)
unnamed: J_TMP36_9Z1.3, TMP36_9Z1.1 (+VS)
unnamed: J_TMP36_TZ1.2, R_PD1.1, TMP36_TZ1.4 (~SHUTDOWN)
unnamed: J_TMP36_TZ1.4, TMP36_TZ1.2 (+VS)
unnamed: J_TMP117.2, R_alert1.2, TMP117.3 (ALERT)
unnamed: J_TMP117.3, R_SDA1.2, TMP117.6 (SDA)
unnamed: J_TMP117.4, R_SCL1.2, TMP117.1 (SCL)

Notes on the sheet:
Without shutdown pin Uses ADC
Digital sensor with high accuracy. Uses I2C
TMP36: SOT-23-5 THP
TMP36: SOT-23-5 SMD
VIN VOUT SHUTDOWN GND
ALERT SDA SCL
With shutdown pin Uses ADC
TMP117

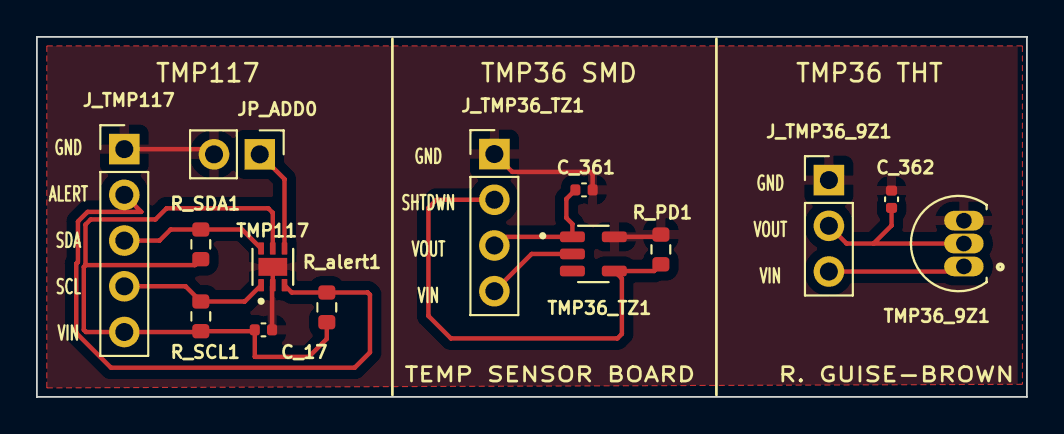
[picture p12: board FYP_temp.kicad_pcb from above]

Board: 2 copper layers, 55.0 x 20.0 mm, 14 parts (0 on the bottom side), 11 nets.

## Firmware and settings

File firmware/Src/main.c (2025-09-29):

/*
 * main.c
 *
 *  Created on: Sep 20, 2025
 *      Author: rachaelguise-brown
 *
 *      Description: Working implementation with modular functions for unified temperature sensing with three selectable methods
 *
 */

#include <stdint.h>
#include <stdbool.h>

// Include created files
#include "led.h"
#include "uart.h"
#include "clock_config.h"
#include "adc_temp.h"
#include "temp_sensor_enable.h"
#include "i2c_temp.h"

// Temperature sensing method selection
typedef enum {
	TMP117_I2C = 1, 			// TMP117 via I2C
	TMP36_WITH_ENABLE = 2,		// TMP36 with shutdown pin control
	TMP36_BASIC = 3				// TMP36 basic (no shutdown control)
}temp_method_t;

// Change this variable to select temperature method
#define SELECTED_TEMP_METHOD 	TMP117_I2C

// Function prototypes
void delay (volatile uint32_t count);
void init_selected_temp_method(temp_method_t method);
void read_display_temp(temp_method_t method, uint32_t counter);
void flash_led_for_method(temp_method_t method);


int main(void)
{
	uint32_t counter = 0;

	//Set clock speed (choose one)
	//Clock_Init(CLOCK_4MHZ);    // HSI 4MHz - default
	Clock_Init(CLOCK_16MHZ);   // MSI 16MHz - 4x faster

	delay(10000);

	// Initialize peripherals
	LED2_Config();
	UART_Init();

	// Initialize the selected temperature sensing method
	init_selected_temp_method(SELECTED_TEMP_METHOD);

	LED2_On();
	delay(10000000);

    // Send startup message
    UART_SendString("=== Temperature Sensor Test ===\r\n");
    UART_SendString("Method: ");

    switch(SELECTED_TEMP_METHOD)
    {
        case TMP117_I2C:
            UART_SendString("TMP117 via I2C (LED: Fast flash)\r\n");
            break;
        case TMP36_WITH_ENABLE:
            UART_SendString("TMP36 with shutdown control (LED: Medium flash)\r\n");
            break;
        case TMP36_BASIC:
            UART_SendString("TMP36 basic (LED: Slow flash)\r\n");
            break;
        default:
            UART_SendString("Unknown method!\r\n");
            break;
    }

    UART_SendString("Clock: ");
    UART_SendNumber(GetClockFreq() / 1000000);
    UART_SendString(" MHz\r\n");
    UART_SendString("LPUART @ ");
    UART_SendNumber(BAUD_RATE);
    UART_SendString(" baud\r\n");
    UART_SendString("-----------------------------\r\n\r\n");

    delay(100000);

    // Flash LED pattern to indicate selected method at startup
    UART_SendString("Indicating selected method with LED pattern...\r\n");
    for(int i = 0; i < 3; i++) {
        flash_led_for_method(SELECTED_TEMP_METHOD);
        delay(2000000); // 2 second pause between pattern repetitions
    }

    while (1)
    {
        counter++;

        if (counter % 10 == 0) // Every 10 seconds
        {
            UART_SendString("=== Temperature Reading - Iteration ");
            UART_SendNumber(counter);
            UART_SendString(" ===\r\n");

            read_display_temp(SELECTED_TEMP_METHOD, counter);

            UART_SendString("\r\n");
        }
        else if (counter % 5 == 0) // Every 5 seconds - status check
        {
            UART_SendString("Status check - iteration ");
            UART_SendNumber(counter);

            switch(SELECTED_TEMP_METHOD) {
                case TMP117_I2C:
                    if (I2C_IsReady())
                    {
                        UART_SendString(": TMP117 I2C METHOD ACTIVE");} else {
                        UART_SendString(", I2C NOT READY");
                    }

                    if (TMP117_IsPresent())
                    {
                        UART_SendString(", TMP117 PRESENT\r\n");
                    } else {
                        UART_SendString(", TMP117 NOT PRESENT\r\n");
                    }
                    break;

                case TMP36_WITH_ENABLE:
                    UART_SendString(": TMP36 WITH ENABLE METHOD ACTIVE\r\n");
                    break;

                case TMP36_BASIC:
                    UART_SendString(": TMP36 BASIC METHOD ACTIVE\r\n");
                    break;

                default:
                    UART_SendString(": UNKNOWN METHOD\r\n");
                    break;
            }
        }

        delay(1000000); // 1 second delay
    }
}

// Initialize the selected temperature sensing method
void init_selected_temp_method(temp_method_t method)
{
    switch(method) {
        case TMP117_I2C:
            // Initialize I2C
            UART_SendString("Initializing I2C...\r\n");
            I2C_Init();
            delay(10000);

            // Check if TMP117 is present
            UART_SendString("Checking for TMP117...\r\n");
            if (TMP117_IsPresent()) {
                UART_SendString("TMP117 found!\r\n");

                // Read device ID to verify
                uint16_t device_id = TMP117_ReadDeviceID();
                UART_SendString("Device ID: ");
                UART_SendHex(device_id);
                if (device_id == TMP117_DEVICE_ID) {
                    UART_SendString(" - CORRECT!\r\n");
                } else {
                    UART_SendString(" - Unexpected (expected 0x0117)\r\n");
                }
            } else {
                UART_SendString("ERROR: TMP117 not found!\r\n");
            }
            UART_SendString("Starting temperature readings...\r\n\r\n");
            break;

        case TMP36_WITH_ENABLE:
            // Initialize ADC and temperature sensor with shutdown control
            ADC_Init();
            TempSensor_Shutdown_Init();
            UART_SendString("TMP36 with shutdown control initialized\r\n");
            break;

        case TMP36_BASIC:
            // Initialize ADC only
            ADC_Init();
            UART_SendString("TMP36 basic initialized\r\n");
            break;

        default:
            UART_SendString("ERROR: Unknown temperature method!\r\n");
            break;
    }
}

// Read and display temperature based on selected method
void read_display_temp(temp_method_t method, uint32_t counter)
{
    switch(method) {
        case TMP117_I2C:
            if (TMP117_IsPresent()) {
                // Read raw temperature
                uint16_t raw_temp = TMP117_ReadRawTemp();

                UART_SendString("Back from temp read, raw value: 0x");
                UART_SendHex(raw_temp);
                UART_SendString("\r\n");

                // Read temperature in Celsius
                UART_SendString("Starting conversion...\r\n");
                int32_t temp_c_hundredths = TMP117_ConvertToTempC(raw_temp);
                UART_SendString("Conversion complete\r\n");

                // Handle negative temperatures correctly
                if (temp_c_hundredths < 0) {
                    // Negative temperature
                    int32_t abs_temp = -temp_c_hundredths;  // Make positive
                    int temp_whole = abs_temp / 10000;      // whole degrees
                    int temp_decimal = (abs_temp % 10000) / 100; // decimal part (hundredths to 2 digits)

                    UART_SendString("Temperature: -");
                    UART_SendNumber(temp_whole);
                    UART_SendChar('.');
                    if (temp_decimal < 10) UART_SendChar('0'); // leading zero for e.g. .05
                    UART_SendNumber(temp_decimal);
                    UART_SendString(" C\r\n");
                } else {
                    // Positive temperature
                    int temp_whole = temp_c_hundredths / 10000;   // whole degrees
                    int temp_decimal = (temp_c_hundredths % 10000) / 100; // decimal part

                    UART_SendString("Temperature: ");
                    UART_SendNumber(temp_whole);
                    UART_SendChar('.');
                    if (temp_decimal < 10) UART_SendChar('0'); // leading zero for e.g. .05
                    UART_SendNumber(temp_decimal);
                    UART_SendString(" C\r\n");
                }

            } else {
                UART_SendString("ERROR: TMP117 not responding!\r\n");
                // Try to reinitialize I2C
                UART_SendString("Attempting to reinitialize I2C...\r\n");
                I2C_Init();
            }
            break;

        case TMP36_WITH_ENABLE:
            // Enable temperature sensor before reading
            TempSensor_Enable();
            delay(10000); // Allow sensor to stabilize

            // Get ADC readings
            uint16_t adc_raw = ADC_Read_Raw();
            uint32_t voltage_mv = ADC_ConvertTo_mV_Precise(adc_raw);

            // Get temperature with better precision
            int32_t temp_tenths = ADC_ConvertTo_TempC_Tenths(adc_raw);

            UART_SendString("Raw ADC: ");
            UART_SendNumber(adc_raw);
            UART_SendString(" (0-4095)\r\n");

            UART_SendString("Voltage: ");
            UART_SendNumber(voltage_mv);
            UART_SendString(" mV\r\n");

            // Display temperature with 1 decimal place
            if (temp_tenths >= 0) {
                int temp_whole = temp_tenths / 10;
                int temp_decimal = temp_tenths % 10;
                UART_SendString("Temperature: ");
                UART_SendNumber(temp_whole);
                UART_SendChar('.');
                UART_SendNumber(temp_decimal);
                UART_SendString(" C\r\n");
            } else {
                int temp_whole = (-temp_tenths) / 10;
                int temp_decimal = (-temp_tenths) % 10;
                UART_SendString("Temperature: -");
                UART_SendNumber(temp_whole);
                UART_SendChar('.');
                UART_SendNumber(temp_decimal);
                UART_SendString(" C\r\n");
            }

            // Disable sensor to save power
            TempSensor_Disable();
            break;

        case TMP36_BASIC:
            // Get ADC readings directly
            uint16_t adc_raw_basic = ADC_Read_Raw();
            uint32_t voltage_mv_basic = ADC_ConvertTo_mV(adc_raw_basic);

            // Get temperature with better precision
            int32_t temp_tenths_basic = ADC_ConvertTo_TempC_Tenths(adc_raw_basic);

            UART_SendString("Raw ADC: ");
            UART_SendNumber(adc_raw_basic);
            UART_SendString(" (0-4095)\r\n");

            UART_SendString("Voltage: ");
            UART_SendNumber(voltage_mv_basic);
            UART_SendString(" mV\r\n");

            // Display temperature with 1 decimal place
            if (temp_tenths_basic >= 0) {
                int temp_whole_basic = temp_tenths_basic / 10;
                int temp_decimal_basic = temp_tenths_basic % 10;
                UART_SendString("Temperature: ");
                UART_SendNumber(temp_whole_basic);
                UART_SendChar('.');
                UART_SendNumber(temp_decimal_basic);
                UART_SendString(" C\r\n");
            } else {
                int temp_whole_basic = (-temp_tenths_basic) / 10;
                int temp_decimal_basic = (-temp_tenths_basic) % 10;
                UART_SendString("Temperature: -");
                UART_SendNumber(temp_whole_basic);
                UART_SendChar('.');
                UART_SendNumber(temp_decimal_basic);
                UART_SendString(" C\r\n");
            }
            break;

        default:
            UART_SendString("ERROR: Unknown temperature method in reading function!\r\n");
            break;
    }
}

// Flash LED with different patterns for each temperature method
void flash_led_for_method(temp_method_t method)
{
    switch(method) {
        case TMP117_I2C:
            // Fast flash pattern: 3 quick flashes
            for(int i = 0; i < 3; i++) {
                LED2_On();
                delay(150000);   // 150ms on
                LED2_Off();
                delay(150000);   // 150ms off
            }
            break;

        case TMP36_WITH_ENABLE:
            // Medium flash pattern: 2 medium flashes
            for(int i = 0; i < 2; i++) {
                LED2_On();
                delay(400000);   // 400ms on
                LED2_Off();
                delay(400000);   // 400ms off
            }
            break;

        case TMP36_BASIC:
            // Slow flash pattern: 1 long flash
            LED2_On();
            delay(1000000);      // 1000ms on
            LED2_Off();
            delay(500000);       // 500ms off
            break;

        default:
            // Error pattern: rapid flashing
            for(int i = 0; i < 5; i++) {
                LED2_On();
                delay(100000);   // 100ms on
                LED2_Off();
                delay(100000);   // 100ms off
            }
            break;
    }
}

// FUNCTIONS
void delay(volatile uint32_t count)
{
    while (count--) {
        asm("nop"); // do nothing (1 CPU cycle)
    }
}

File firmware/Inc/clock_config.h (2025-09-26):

/*
 * clock_config.h
 *
 *  Created on: Sep 20, 2025
 *      Author: rachaelguise-brown
 *
 *      Description: Clock configuration and management - kept SIMPLE
 */

#ifndef CLOCK_CONFIG_H_
#define CLOCK_CONFIG_H_

#include <stdint.h>

// Clock configuration options
typedef enum
{
	CLOCK_4MHZ = 0, 	// Default after reset
	CLOCK_16MHZ, 		// Faster MSI
}Clock_Config_t;

// Function prototypes
void Clock_Init(Clock_Config_t config);
uint32_t GetClockFreq(void);

// Helper macros for common frequencies
#define FREQ_4MHZ 	4000000UL
#define FREQ_16MHZ 	16000000UL

// Base addresses
#define RCC_BASE 0x40021000U

// RCC registers
#define RCC_CR       (*(volatile uint32_t*)(RCC_BASE + 0x00))
#define RCC_ICSCR    (*(volatile uint32_t*)(RCC_BASE + 0x04))
#define RCC_CFGR     (*(volatile uint32_t*)(RCC_BASE + 0x08))
#define RCC_CCIPR    (*(volatile uint32_t*)(RCC_BASE + 0x88))

// RCC_CR bit definitions
#define RCC_CR_HSION_Pos    (8U)
#define RCC_CR_HSION        (1UL << RCC_CR_HSION_Pos)
#define RCC_CR_HSIRDY_Pos   (10U)
#define RCC_CR_HSIRDY       (1UL << RCC_CR_HSIRDY_Pos)
#define RCC_CR_MSION_Pos    (0U)
#define RCC_CR_MSION        (1UL << RCC_CR_MSION_Pos)
#define RCC_CR_MSIRDY_Pos   (1U)
#define RCC_CR_MSIRDY       (1UL << RCC_CR_MSIRDY_Pos)
#define RCC_CR_MSIRANGE_Pos (4U)
#define RCC_CR_MSIRANGE     (0xFUL << RCC_CR_MSIRANGE_Pos)
#define RCC_CR_MSIRGSEL_Pos (3U)
#define RCC_CR_MSIRGSEL     (1UL << RCC_CR_MSIRGSEL_Pos)

// RCC_CFGR bit definitions
#define RCC_CFGR_SW_Pos     (0U)
#define RCC_CFGR_SW         (0x3UL << RCC_CFGR_SW_Pos)
#define RCC_CFGR_SW_MSI     (0x0UL << RCC_CFGR_SW_Pos)
#define RCC_CFGR_SW_HSI16   (0x1UL << RCC_CFGR_SW_Pos)
#define RCC_CFGR_SWS_Pos    (2U)
#define RCC_CFGR_SWS        (0x3UL << RCC_CFGR_SWS_Pos)
#define RCC_CFGR_SWS_MSI    (0x0UL << RCC_CFGR_SWS_Pos)
#define RCC_CFGR_SWS_HSI16  (0x1UL << RCC_CFGR_SWS_Pos)

// RCC_CCIPR bit definitions (for ADC clock source)
#define RCC_CCIPR_ADCSEL_Pos (28U)
#define RCC_CCIPR_ADCSEL     (0x3UL << RCC_CCIPR_ADCSEL_Pos)
#define RCC_CCIPR_ADCSEL_NONE (0x0UL << RCC_CCIPR_ADCSEL_Pos)
#define RCC_CCIPR_ADCSEL_SYSCLK (0x1UL << RCC_CCIPR_ADCSEL_Pos)


#endif /* CLOCK_CONFIG_H_ */

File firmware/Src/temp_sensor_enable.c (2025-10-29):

/*
 * temp_sensor_enable.c
 *
 *  Created on: Sep 26, 2025
 *      Author: rachaelguise-brown
 *
 *      Implementation to enable Shutdown pin on Temp Sensor
 */

#include "temp_sensor_enable.h"
#include "uart.h"
#include "adc_temp.h"

/**
 * @brief Initialize PG0 as output for temperature sensor shutdown control
 * on C9 - pin 29 (bottom left)
 */
void TempSensor_Shutdown_Init(void)
{
    UART_SendString("Initializing PG0 for temperature sensor shutdown control...\r\n");

    // Enable GPIOG clock
    RCC_AHB2ENR |= RCC_AHB2ENR_GPIOG_EN;

    // Wait for clock to stabilize
    for (volatile int i = 0; i < 1000; i++);

    // Configure PG0 as output
    // Clear mode bits for PG0 (bits 1:0)
    TEMP_GPIOG_MODER &= ~(3U << (TEMP_SHUTDOWN_PIN * 2));
    // Set as output (01)
    TEMP_GPIOG_MODER |= (1U << (TEMP_SHUTDOWN_PIN * 2));

    // Configure as push-pull output (default, but explicit)
    TEMP_GPIOG_OTYPER &= ~(1U << TEMP_SHUTDOWN_PIN);

    // Set medium speed
    TEMP_GPIOG_OSPEEDR &= ~(3U << (TEMP_SHUTDOWN_PIN * 2));
    TEMP_GPIOG_OSPEEDR |= (1U << (TEMP_SHUTDOWN_PIN * 2));

    // No pull-up/pull-down
    TEMP_GPIOG_PUPDR &= ~(3U << (TEMP_SHUTDOWN_PIN * 2));

    // Start with sensor disabled (shutdown pin LOW)
    TempSensor_Disable();

    UART_SendString("PG0 configured as output for temperature sensor shutdown\r\n");
}

/**
 * @brief Enable temperature sensor (set PG0 HIGH)
 */
void TempSensor_Enable(void)
{
    // Set PG0 high using BSRR register (atomic set)
    TEMP_GPIOG_BSRR = (1U << TEMP_SHUTDOWN_PIN);

    // Give sensor time to stabilize after enabling
    for (volatile int i = 0; i < 20000; i++);  // ~1ms at 16MHz

    // Optional debug message (comment out for less verbose output)
    //UART_SendString("Temperature sensor enabled\r\n");
}

/**
 * @brief Disable temperature sensor (set PG0 LOW)
 */
void TempSensor_Disable(void)
{
    // Clear PG0 using BSRR register (atomic clear)
    TEMP_GPIOG_BSRR = (1U << (TEMP_SHUTDOWN_PIN + 16));

    // Optional debug message (comment out for less verbose output)
    // UART_SendString("Temperature sensor disabled\r\n");
}

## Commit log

2025-09-26 LED, UART and ADC
2025-09-26 temp sensor enable
2025-09-28 I2C with temp sensor intial communication
2025-09-28 I2C with temperature readings working + debugging
2025-09-28 All temp sensors working with main.c code
2025-09-29 new file name for i2c_temp
2025-10-10 Battery monitoring combined
2025-10-13 BMS full algorithm and battery monitoring
2025-10-29 KiCad component files
2025-10-29 KiCad Temp PCB
    [BOM-FYP_temp.csv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]
2025-10-29 KiCad BQ35100 board
    [BOM-FYP_PMIC.csv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]
2025-10-29 KiCAD INA226 board
    [STM_Nucleo_Hat.kicad_pcb, STM_Nucleo_Hat.kicad_sch, bom.csv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]
2025-10-29 STM32 User manual
